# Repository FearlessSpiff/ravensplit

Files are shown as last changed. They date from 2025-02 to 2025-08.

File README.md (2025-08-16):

# ravensplit

(MX) Low profile split version of the raveniung

## Setup

* Install ergogen: `npm install -g ergogen`
* Get footprints from ceoloide: `git clone https://github.com/ceoloide/ergogen-footprints ergogen/footprints/ceoloide`
* For case build install `npm install -g @jscad/cli`

## Build

```bash
cd ergogen
ergogen .
```

or for building including the left case:

```bash
ergogen . && npx @jscad/cli@1 output/cases/LeftCase.jscad -of stla
```

## Notes

* mirror right case and cirque holder!

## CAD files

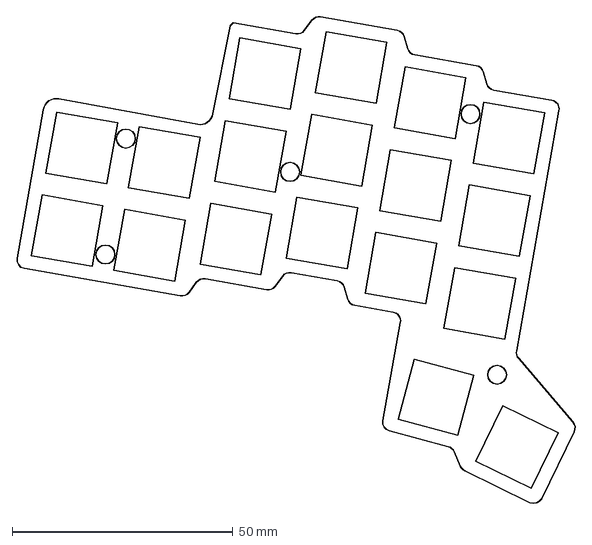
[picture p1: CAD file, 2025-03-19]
v0.1/Outlines/top-foam-plate.dxf
126.9 x 110.7 mm

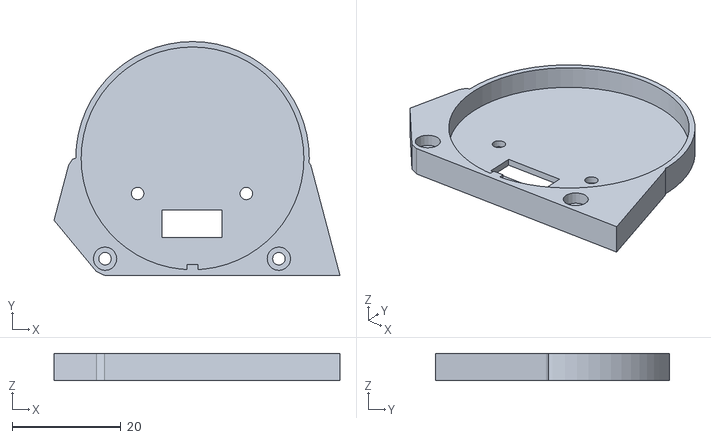
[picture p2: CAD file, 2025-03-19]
v0.1/STLs/Ravensplit Cirque Curved 35mm.stl
52.6 x 43.1 x 5.00

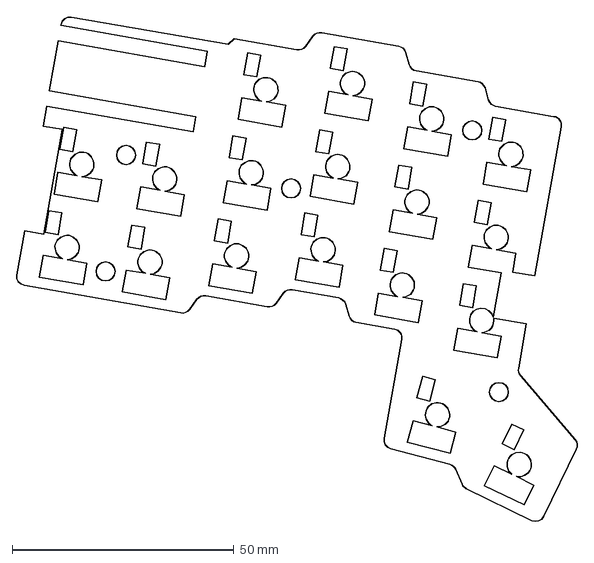
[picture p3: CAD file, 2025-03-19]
v0.1/Outlines/bottom-foam-plate-right.dxf
126.9 x 114.3 mm

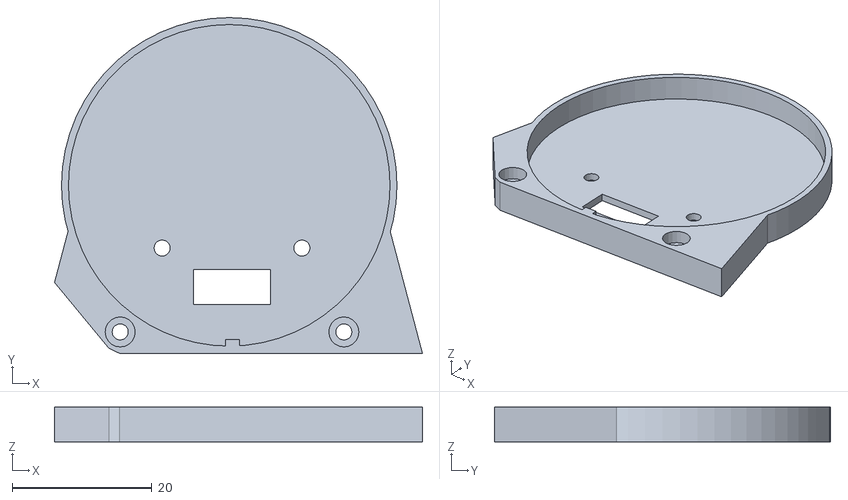
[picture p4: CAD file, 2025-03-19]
v0.1/STLs/Ravensplit Cirque Curved 40mm.stl
52.6 x 48.1 x 5.00

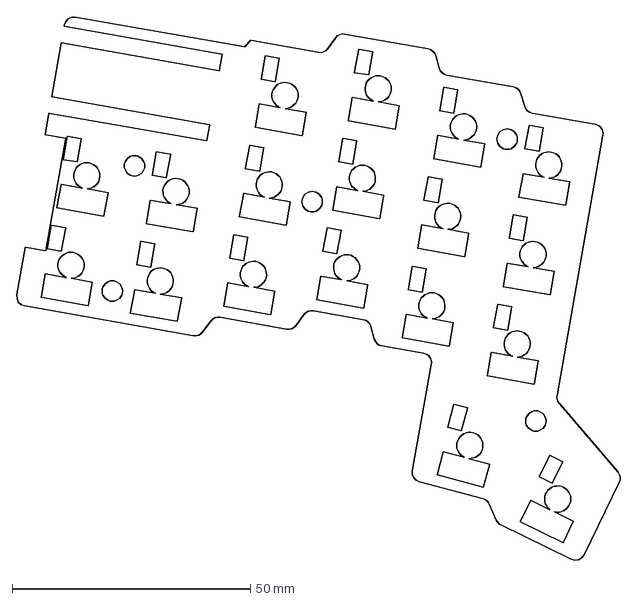
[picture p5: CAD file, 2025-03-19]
v0.1/Outlines/bottom-foam-plate-left.dxf
126.9 x 114.3 mm

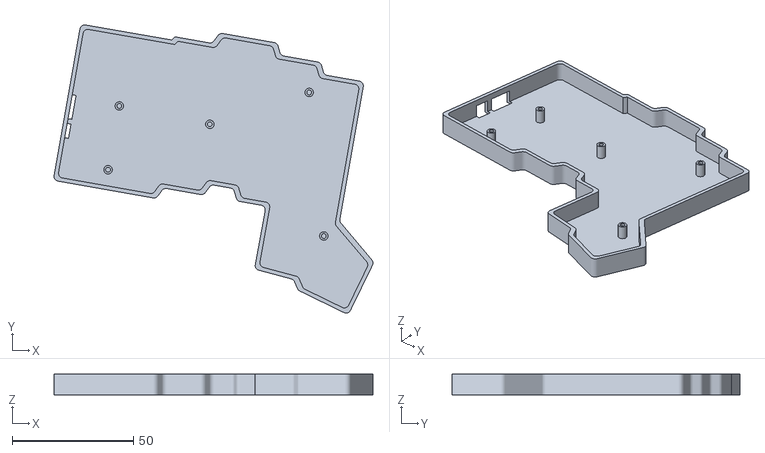
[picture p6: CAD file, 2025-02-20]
v0.1/STLs/left-case.stl
131.3 x 118.6 x 8.50

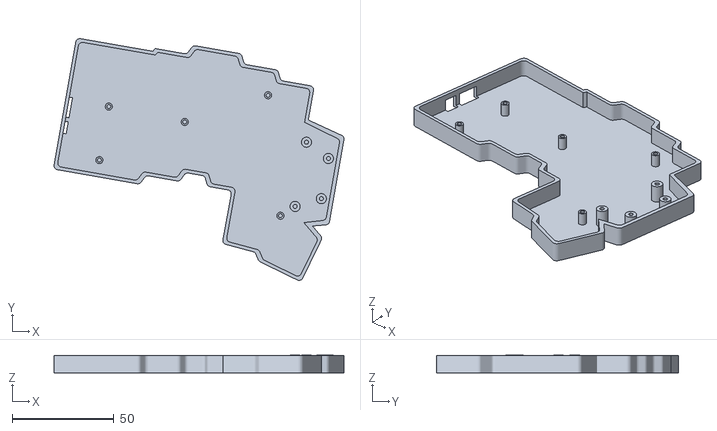
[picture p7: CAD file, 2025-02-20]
v0.1/STLs/right-case-mirror.stl
142.3 x 118.6 x 8.60

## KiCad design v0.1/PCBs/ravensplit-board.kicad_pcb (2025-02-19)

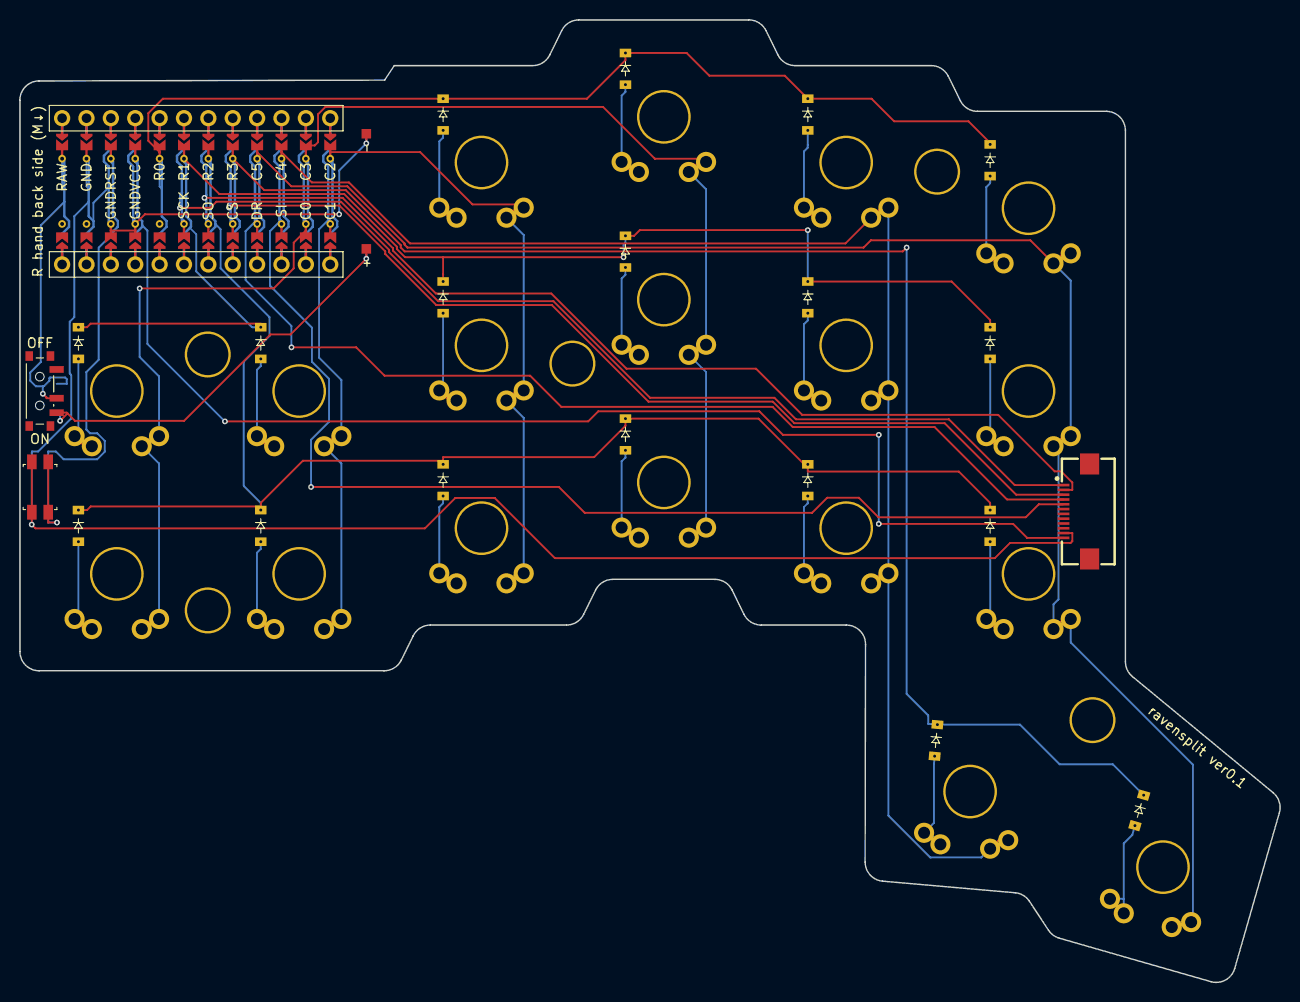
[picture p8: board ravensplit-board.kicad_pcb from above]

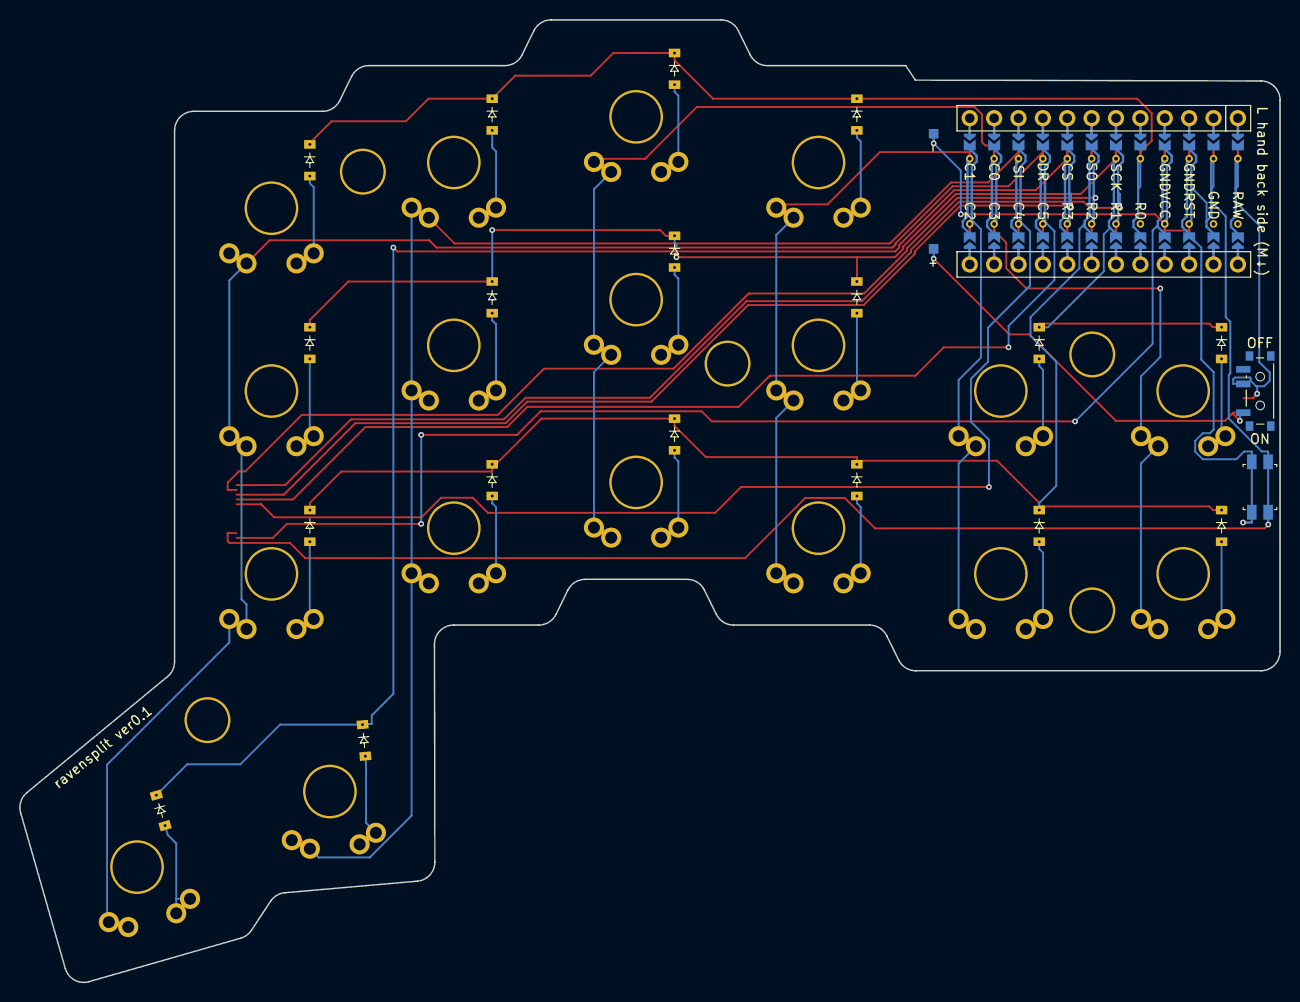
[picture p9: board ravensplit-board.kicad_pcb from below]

Board: 2 copper layers, 131.3 x 100.3 mm, 47 parts (18 on the bottom side), 38 nets.

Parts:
D1, D2, D3, D4, D5, D6, D7, D8, D9, D10, D11, D12, D13, D14, D15, D16, D17, D18: diode_tht_sod123
FFC1: FPC-SMD_FPC05012-09200
MCU1: mcu_nice_nano
MH1, MH2, MH3, MH4, MH5: mounting_hole_npth
PAD1, PAD2: SMDPad
PWR1: power_switch_smd_side
RST1: reset_switch_smd_side
S1, S2, S3, S4, S5, S6, S7, S8, S9, S10, S11, S12, S13, S14, S15, S16, S17, S18: switch_gateron_ks27_ks33

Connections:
BAT_P: PAD1.1, PWR1.1, PWR1.3
C0: MCU1.114, S1.2, S2.2
C1: MCU1.113, S3.2, S4.2
C2: MCU1.112, S5.2, S6.2, S7.2
C3: MCU1.111, S8.2, S9.2, S10.2
C4: MCU1.110, S11.2, S12.2, S13.2, S18.2
C5: MCU1.109, S14.2, S15.2, S16.2, S17.2
CS: FFC1.3, MCU1.117
DR: FFC1.4, MCU1.116
GND: FFC1.11, MCU1.102, MCU1.121, MCU1.122, PAD2.1, RST1.1, RST1.3
R0: D7.1, D10.1, D13.1, D16.1, MCU1.105
R1: D2.1, D4.1, D6.1, D9.1, D12.1, D15.1, MCU1.106
R2: D1.1, D3.1, D5.1, D8.1, D11.1, D14.1, MCU1.107
R3: D17.1, D18.1, MCU1.108
RAW: MCU1.101, PWR1.2
RST: MCU1.103, RST1.2, RST1.4
SCK: FFC1.1, MCU1.119
SI: FFC1.5, MCU1.115
SO: FFC1.2, MCU1.118
VCC: FFC1.12, MCU1.104
index_bottom: D11.2, S11.1
index_home: D12.2, S12.1
index_top: D13.2, S13.1
inner_bottom: D14.2, S14.1
inner_home: D15.2, S15.1
inner_thumb: D17.2, S17.1
inner_top: D16.2, S16.1
middle_bottom: D8.2, S8.1
middle_home: D9.2, S9.1
middle_top: D10.2, S10.1
outer_bottom: D1.2, S1.1
outer_home: D2.2, S2.1
pinky_bottom: D3.2, S3.1
pinky_home: D4.2, S4.1
reachy_thumb: D18.2, S18.1
ring_bottom: D5.2, S5.1
ring_home: D6.2, S6.1
ring_top: D7.2, S7.1

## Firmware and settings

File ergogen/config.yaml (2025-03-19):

units:
  angle: -10
  P: 0.53U
  caseOuter: 1.9
  caseInner: 0.3
  caseStandoffRadius: 1.75
  cirqueStandoffRadius: 2.1
  caseHoleRadius: 1
points:
  zones:
    matrix:
      # Fix placement on KiCAD sheet.
      anchor:
        shift: [100, -100]
      rotate: angle
      columns:
        outer:
          key:
            column_net: C0
          rows:
            top:
              skip: true
        pinky:
          key:
            column_net: C1
          rows:
            top:
              skip: true
        ring:
          key:
            stagger: 0.25U
            column_net: C2
        middle:
          key:
            stagger: 0.25U
            column_net: C3
        index:
          key:
            stagger: -0.25U
            column_net: C4
        inner:
          key:
            stagger: -0.25U
            column_net: C5
      rows:
        bottom:
          padding: U
          row_net: R2
        home:
          padding: U
          row_net: R1
        top:
          padding: U
          row_net: R0
    thumbs:
      anchor:
        ref: matrix_inner_bottom
        shift: [0.75U, -1.5U]
        rotate: -8
      columns:
        inner:
          key:
            rotate: -8
            shift: [0, -2]
            column_net: C5
        reachy:
          key:
            rotate: 3
            shift: [-40, 3]
            column_net: C4
      rows:
        thumb:
          row_net: R3
    mount-hole-inner-top:
      anchor:
        ref: matrix_inner_top
        shift: [-0.5U, 0.2U]
      key:
        name: mount-hole-inner-top
        width: 1
        height: 1
    mount-hole-inner-bottom:
      anchor:
        ref: matrix_inner_bottom
        shift: [.35U, -0.8U]
      key:
        name: mount-hole-inner-bottom
        width: 1
        height: 1
    mount-hole-middle-home:
      anchor:
        ref: matrix_middle_home
        shift: [-0.5U, -0.35U]
      key:
        name: mount-hole-middle-home
        width: 1
        height: 1
    mount-hole-pinky-home:
      anchor:
        ref: matrix_pinky_home
        shift: [-0.5U, 0.2U]
      key:
        name: mount-hole-pinky-home
        width: 1
        height: 1
    mount-hole-pinky-bottom:
      anchor:
        ref: matrix_pinky_bottom
        shift: [-0.5U, -0.2U]
      key:
        name: mount-hole-pinky-bottom
        width: 1
        height: 1
    ffc12-footprint:
      anchor:
        ref: matrix_inner_bottom
        shift: [5, 6.5]
      key:
        name: ffc12-footprint
        width: 1
        height: 1
    cirque-hole-top-right:
      anchor:
        ref: ffc12-footprint
        shift: [20, -10]
      key:
        name: cirque-hole-top-right
        width: 1
        height: 1
    cirque-hole-top-left:
      anchor:
        ref: ffc12-footprint
        shift: [8, 16]
      key:
        name: cirque-hole-top-left
        width: 1
        height: 1
    cirque-hole-bottom-left:
      anchor:
        ref: ffc12-footprint
        shift: [8, -16]
      key:
        name: cirque-hole-bottom-left
        width: 1
        height: 1
    cirque-hole-bottom-right:
      anchor:
        ref: ffc12-footprint
        shift: [20, 10]
      key:
        name: cirque-hole-bottom-right
        width: 1
        height: 1
    mcu-footprint:
      anchor:
        ref: matrix_ring_top
        shift: [-31, -3]
      key:
        name: mcu-footprint
        width: 1
        height: 1
    power-switch-footprint:
      anchor:
        ref: matrix_outer_home
        shift: [-8, 0]
      key:
        name: power-switch-footprint
        width: 1
        height: 1
    reset-switch-footprint:
      anchor:
        ref: matrix_outer_home
        shift: [-8, -10]
      key:
        name: reset-switch-footprint
        width: 1
        height: 1
    battery-pad-plus-mcu-footprint:
      anchor:
        ref: mcu-footprint
        shift: [19, -6]
      key:
        name: battery-pad-plus-mcu-footprint
        width: 1
        height: 1
    battery-pad-minus-mcu-footprint:
      anchor:
        ref: mcu-footprint
        shift: [19, 6]
      key:
        name: battery-pad-minus-mcu-footprint
        width: 1
        height: 1
outlines:
  keycaps:
    - what: rectangle
      where:
        - /matrix_.*/
        - /thumbs_.*/
      size: [U-0.5, U-0.5]
  keys:
    - what: rectangle
      where:
        - /matrix_.*/
        - /thumbs_.*/
      size: [14, 14]
  keys-stem-footprint:
    - what: circle
      where:
        - /matrix_.*/
        - /thumbs_.*/
      radius: 2.75
  keys-footprint:
    - what: rectangle
      where:
        - /matrix_.*/
        - /thumbs_.*/
      size: [10, 5]
      adjust:
        shift: [0, -5.2]
  diodes-footprint:
    - what: rectangle
      where:
        - /matrix_.*/
        - /thumbs_.*/
      size: [3, 5]
      adjust:
        shift: [-4, 5]
  board:
    - what: polygon
      operation: stack
      fillet: 2
      points:
        - ref: matrix_outer_home
          shift: [-P, 3.2P]
        - ref: matrix_ring_top
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

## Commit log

2025-02-06 Add initial version
    TODO:
    - battery connector
    - mcu top cutout
    - top-plate
    - foam-plates
    - cases
    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
2025-02-07 fix mount hole and top plate
    [config.yaml]
2025-02-07 "Almost" finished ergogen PCB definition
2025-02-07 Remove unused mount hole
2025-02-07 Fix untested bottom foam plate
    [config.yaml]
2025-02-09 Add outlines to define a case wall
2025-02-09 Add first (maybe) usable case without mounting holes yet
2025-02-10 Add standoffs to case
2025-02-10 Change to smaller footprint and tighter case tolerance
    [config.yaml]
2025-02-10 Make board bigger for the MCU
2025-02-10 Add right case with cirque extension (must be mirrored before printing)
2025-02-10 Fix cirque standoff height
    [config.yaml]
2025-02-11 "Final" version for the cirque holder. STL follows...
2025-02-11 Add not yet measured case cutouts for power- and reset switch
2025-02-12 Nicer case cutouts for switches
2025-02-12 Adapt pcb components to smaller footprint
2025-02-12 Remove PCB top plate label for a clean black look
2025-02-13 Fix thumb columns, easier routing for MCU, and fix label
    [config.yaml]
2025-02-13 Add a maybe finished PCB for v0.1
    [ravensplit-board.kicad_pcb, ravensplit-top-plate.kicad_pcb]
2025-02-14 Center MCU better and auto redo PCBs
    [ravensplit-board.kicad_pcb, ravensplit-top-plate.kicad_pcb]
2025-02-14 Fix ugly route around diode
    [ravensplit-board.kicad_pcb]
2025-02-14 Fix FFC connector orientation
    [ravensplit-board.kicad_pcb]
2025-02-14 Add correct routed PCB with DRC ran
    [ravensplit-board.kicad_pcb]
2025-02-14 Add text on both sides of PCB
    [ravensplit-board.kicad_pcb]
2025-02-14 Fix an obvious ugly rout from auto routing
    [ravensplit-board.kicad_pcb]
2025-02-19 Add some more KiCad stuff to .gitignore
2025-02-19 Add forgotten mirrored FFC connector
2025-02-19 Add final and ordered V0.1 PCBs and gerber files
    [ravensplit-board.kicad_pcb, ravensplit-top-plate.kicad_pcb]
2025-02-19 Add untested bottom foam plate
2025-02-20 Add a right and left bottom foam plate
2025-02-20 Add STLs for cases and cirque adapter
    [cirque-40mm-curved-mirror-for-right-side.stl, left-case.stl, right-case-mirror.stl]
2025-02-27 Better bottom foam plate
2025-03-07 Add 35mm cirque stl
    [Ravensplit Cirque Curved 35mm.stl]
2025-03-19 Updates for v0.1
    [Ravensplit Cirque Curved 35mm.stl, Ravensplit Cirque Curved 40mm.stl, bottom-foam-plate-left.dxf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]
